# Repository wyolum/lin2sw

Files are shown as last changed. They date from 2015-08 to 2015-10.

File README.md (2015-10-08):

# lin2sw
small board to convert linear 3 pin regulator to switching regulator (TO220 compatible, eg 7805)

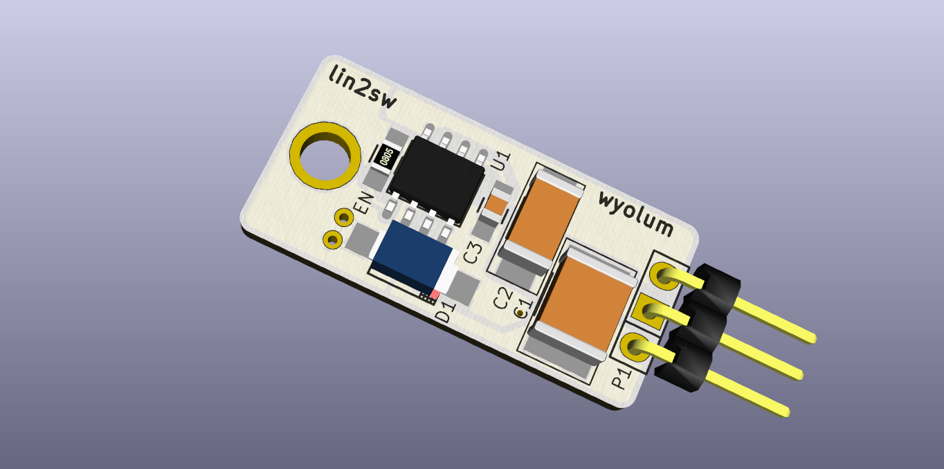
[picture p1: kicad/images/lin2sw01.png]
lin2sw Front render


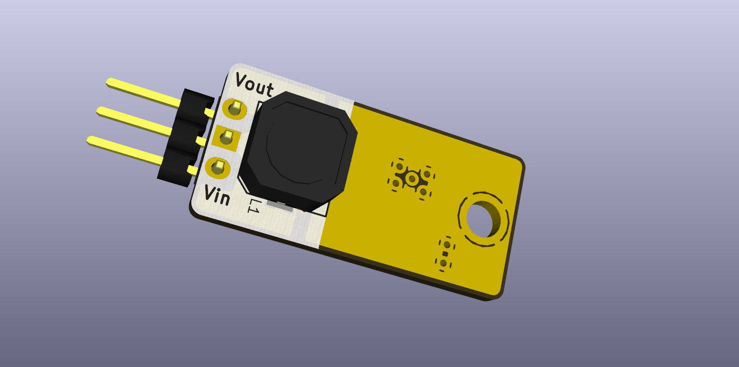
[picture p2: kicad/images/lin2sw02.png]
lin2sw Back render


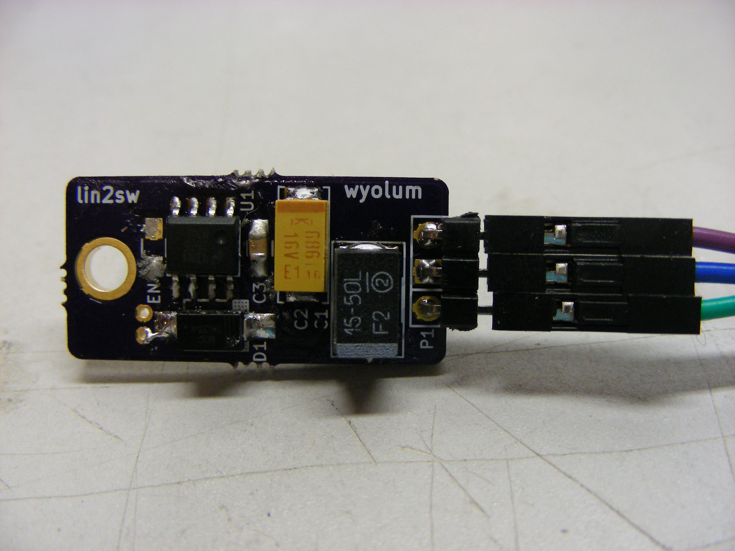
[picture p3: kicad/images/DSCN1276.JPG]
lin2sw Front


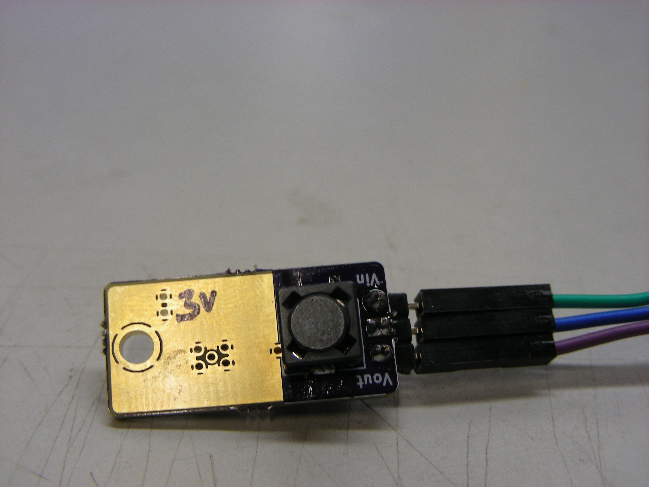
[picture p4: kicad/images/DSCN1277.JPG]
lin2sw Back


License
-------
[CERN Open Hardware Licence v1.2 ]

[CERN Open Hardware Licence v1.2 ]:http://www.ohwr.org/attachments/2388/cern_ohl_v_1_2.txt

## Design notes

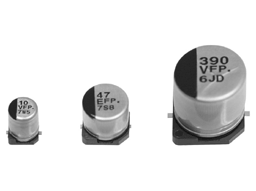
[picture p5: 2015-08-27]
kicad/datasheets/EEEFP1C331AP _ FP (High temp. reflow) _ Industrial Devices & Solutions _ Panasonic_files/ABA0000SC114.gif

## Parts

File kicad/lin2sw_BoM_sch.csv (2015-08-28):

Reference | Value | Footprint | Datasheet
U1 | LM2675-5.0 | lin2sw:SO-8
C1 | 15uF 50V | lin2sw:C_2917_HandSoldering
C2 | 68uF 16V | lin2sw:C_2312_HandSoldering
L1 | 33uH | lin2sw:Choke_SMD_Pulse-PE1167
C3 | 10nF | lin2sw:C_0805_HandSoldering
D1 | SK35 | lin2sw:Diode-SMA_Handsoldering
P1 | TO220 | lin2sw:Pin_Header_Straight_1x03
W1 | EN | lin2sw:R_0805_HandSoldering

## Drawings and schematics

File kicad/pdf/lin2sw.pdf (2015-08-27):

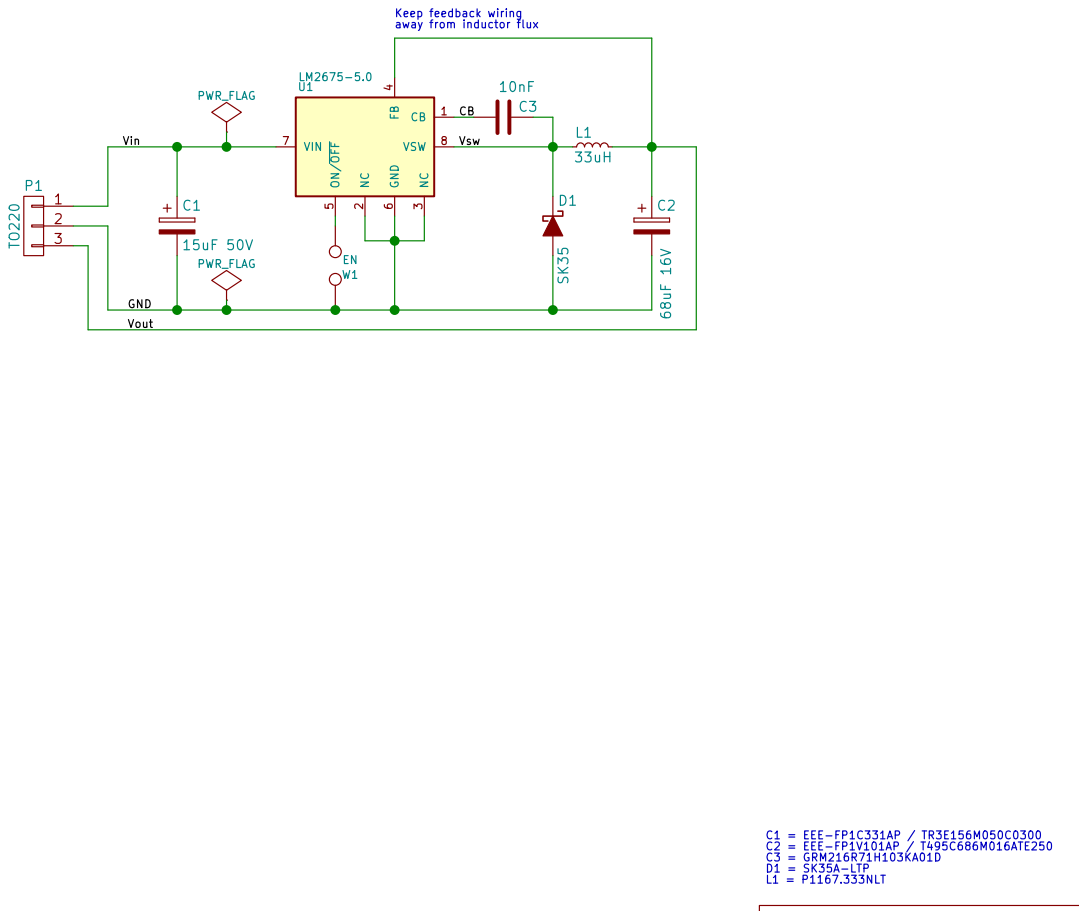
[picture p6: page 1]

Keep feedback wiring
away from inductor flux

Id: 1/1 Title: lin2sw - linear regulator to switcher converter File: lin2sw.sch Sheet: / WyoLum

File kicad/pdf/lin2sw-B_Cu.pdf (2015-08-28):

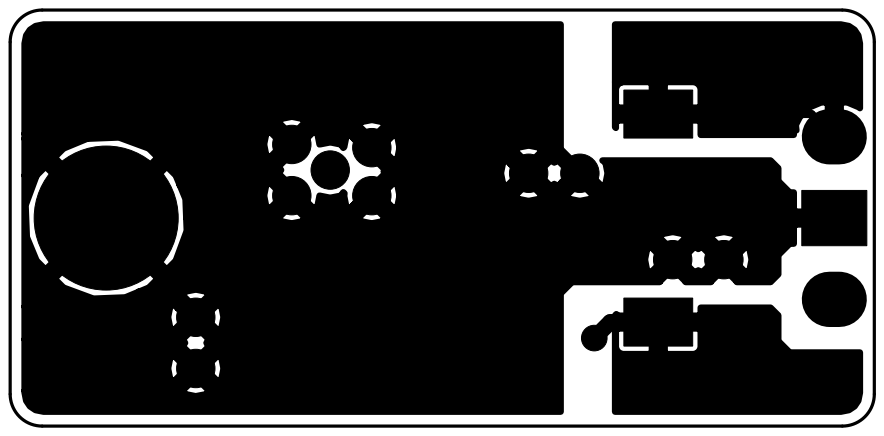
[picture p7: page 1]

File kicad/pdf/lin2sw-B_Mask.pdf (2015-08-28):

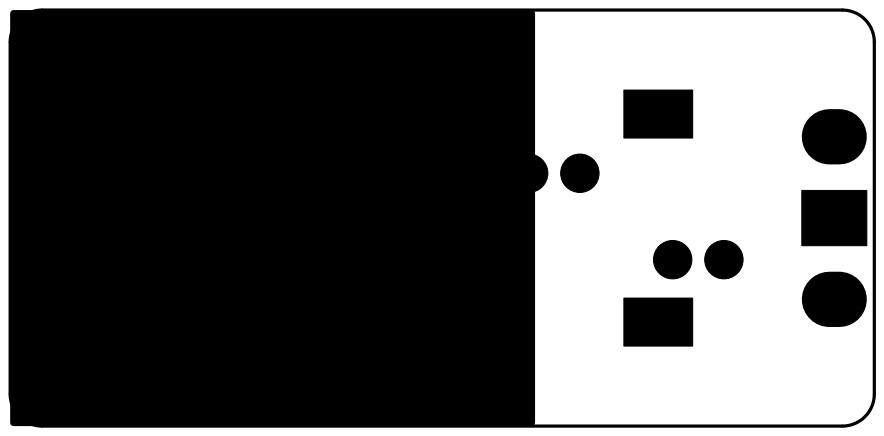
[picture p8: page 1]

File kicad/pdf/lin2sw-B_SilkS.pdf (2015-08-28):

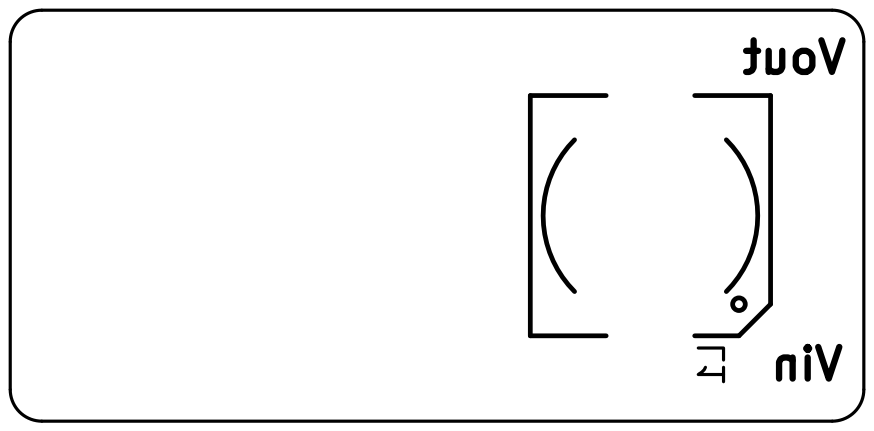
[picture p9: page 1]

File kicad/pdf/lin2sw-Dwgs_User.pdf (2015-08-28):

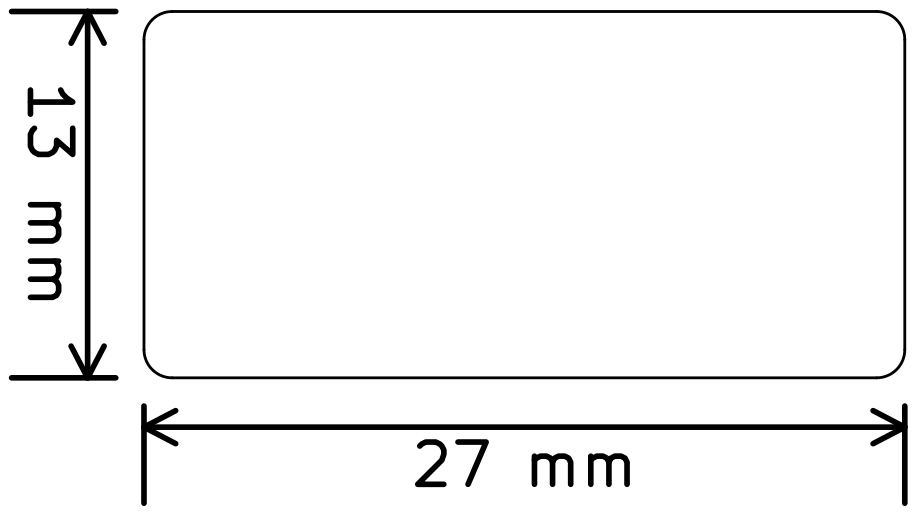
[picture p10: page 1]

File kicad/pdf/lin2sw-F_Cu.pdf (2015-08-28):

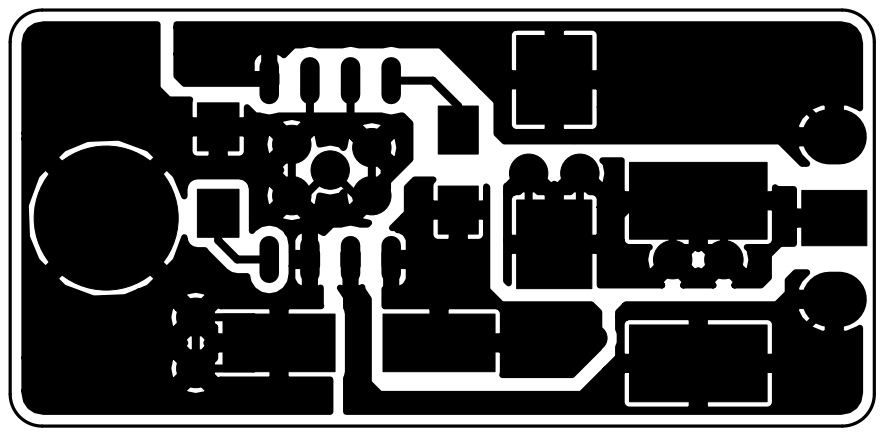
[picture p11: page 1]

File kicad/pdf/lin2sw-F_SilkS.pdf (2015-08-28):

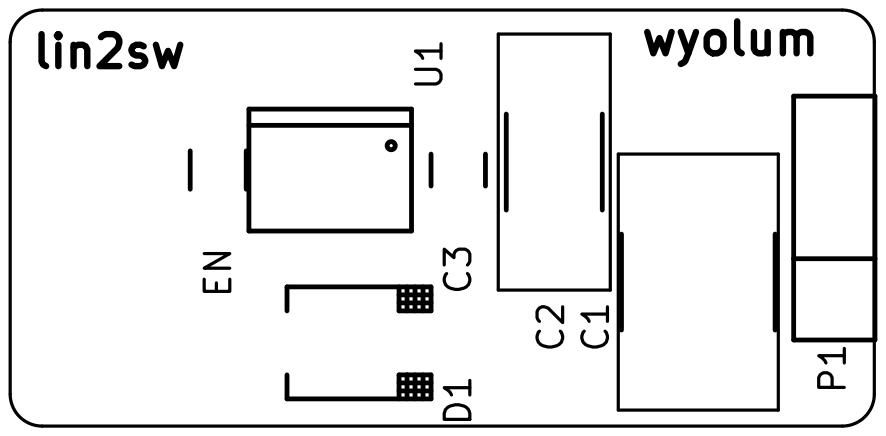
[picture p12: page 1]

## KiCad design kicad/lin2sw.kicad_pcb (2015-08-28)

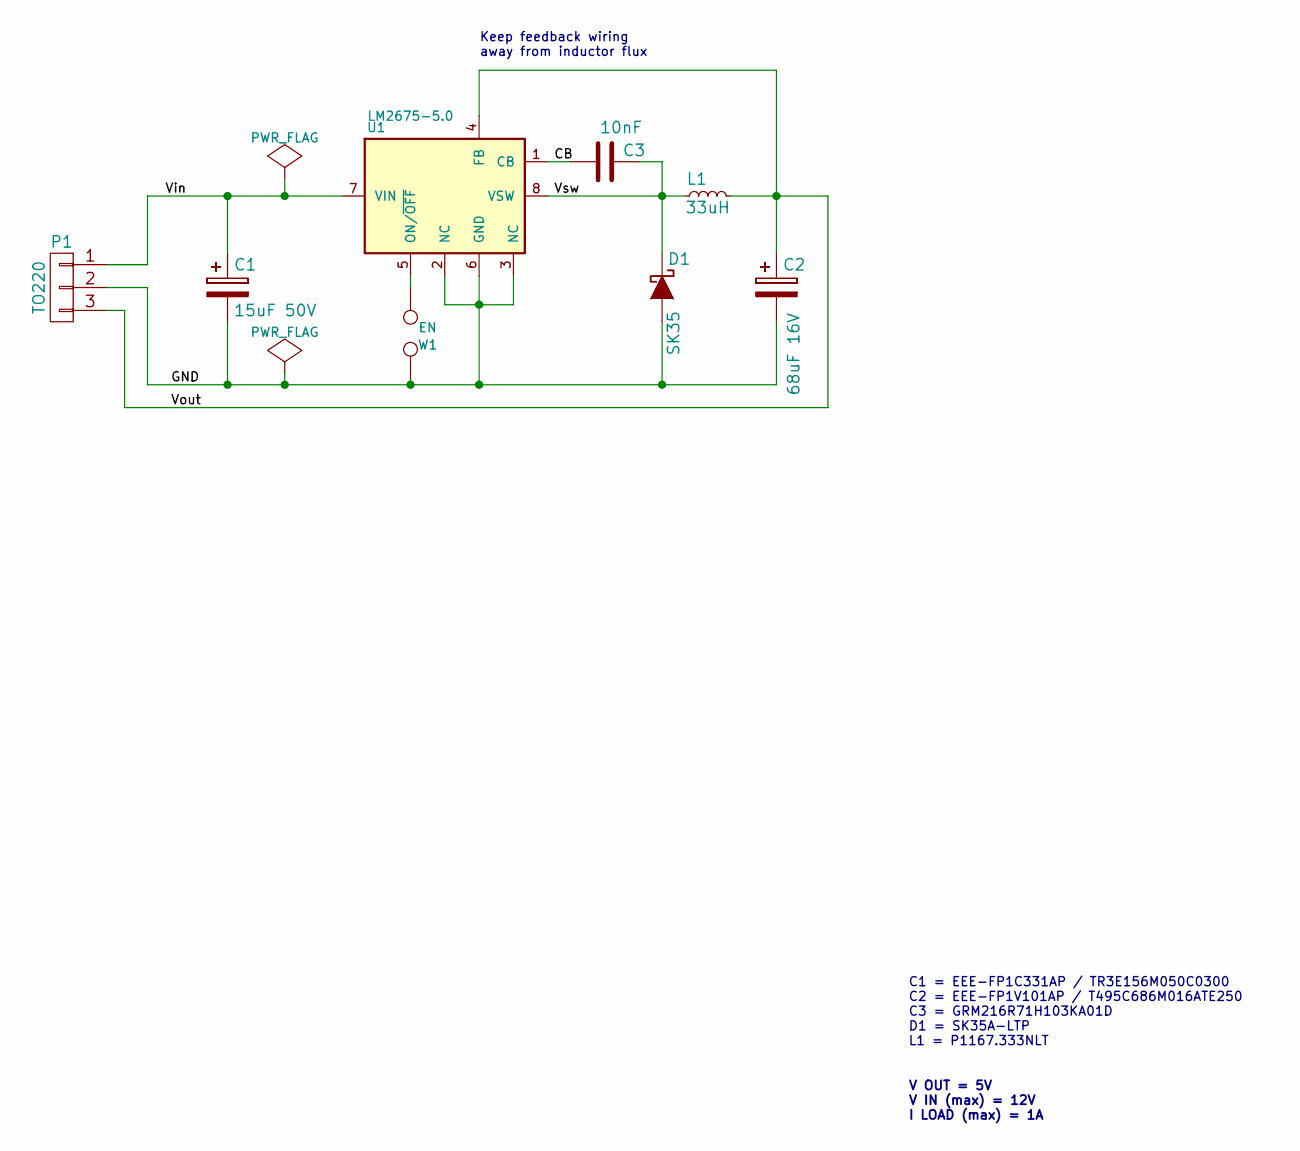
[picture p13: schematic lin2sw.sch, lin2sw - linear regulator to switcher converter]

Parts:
C1: 15uF 50V; C_2917_HandSoldering
C2: 68uF 16V; C_2312_HandSoldering
C3: 10nF; C_0805_HandSoldering
D1: SK35; Diode-SMA_Handsoldering
L1: 33uH; Choke_SMD_Pulse-PE1167
P1: TO220; Pin_Header_Straight_1x03
U1: LM2675-5.0; SO-8
W1: EN; R_0805_HandSoldering

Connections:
/CB: C3.2, U1.1 (CB)
/GND: C1.2, C2.2, D1.1 (A), P1.2, U1.2 (NC), U1.3 (NC), U1.6 (GND), W1.2
/Vin: C1.1, P1.1, U1.7 (VIN)
/Vout: C2.1, L1.2, P1.3, U1.4 (FB)
/Vsw: C3.1, D1.2 (K), L1.1, U1.8 (VSW)
unnamed: U1.5 (ON/~OFF), W1.1

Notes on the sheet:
Keep feedback wiring away from inductor flux
V OUT = 5V V IN (max) = 12V I LOAD (max) = 1A
C1 = EEE-FP1C331AP / TR3E156M050C0300 C2 = EEE-FP1V101AP / T495C686M016ATE250 C3 = GRM216R71H103KA01D D1 = SK35A-LTP L1 = P1167.333NLT

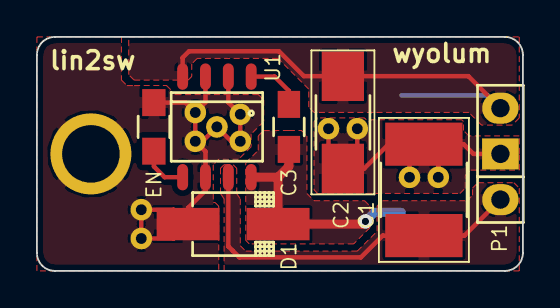
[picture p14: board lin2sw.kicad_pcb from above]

Board: 2 copper layers, 27.0 x 13.0 mm, 8 parts (1 on the bottom side), 6 nets.

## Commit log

2015-08-27 added gerbers
    [lin2sw-B_Cu.gbl, lin2sw-B_Mask.gbs, lin2sw-B_SilkS.gbo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]
2015-08-28 minor mods to layout. Gerbers ready for fab
    [lin2sw-B_Cu.gbl, lin2sw-B_Mask.gbs, lin2sw-B_SilkS.gbo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]
2015-09-23 added pictures of finished boards
